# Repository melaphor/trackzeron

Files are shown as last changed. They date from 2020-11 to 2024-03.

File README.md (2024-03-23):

## ***Update 2024 March 23:* Archiving this repo** 
I was very passionate about this project when I started it in 2020, but I am no longer working on it. 

Both Azeron and QMK have made leaps and bounds in the past few years, so this incarnation of the project is behind the times. 

I think it's well past time for me to officially pass the torch to [chrisistansell](https://github.com/chrisistansell). He's adapted it for the Cyborg ***and*** adjusted the holder for a 34mm trackball, which is way more common and easily accessible than the 52mm* I used. 

**Note (because it's been asked often): I used 52mm because I wanted a very large trackball and was only considering my personal use when I started the project.*

# TRACKzeron: Adding trackball functionality to the [Azeron Keypad](https://www.azeron.eu/)

This repository contains source code and prebuilt firmware files for a modified Azeron keypad.



## Only for Classic and Compact models with TEENSY++ 2.0 mainboards

**This does not work with the Cyborg/Cyborg compact models.** It is for Azeron classic devices that use the Teensy++ 2.0 (green) mainboard. The Teensy++ 2.0 was discontinued in 2021, and Azeron started producing models with their proprietary ARM/STM32-based (black) mainboard in late-2022. I will not be adding support for the Azeron proprietary mainboards ~~and there is no ETA on a mod for Cyborg models with Teensy mainboards.~~ [Check out chrisistansell's fork for Teensy-based Cyborg support.](https://github.com/chrisistansell)

## Notes

-   This mod has no official Azeron support.
-   I had to compile custom firmware to make the trackball work, so this modded keypad does not work with the official Azeron software.
-   This mod requires soldering. (No soldering to anything on the keypad, just the sensor module)   
-   Modifying your device always comes with risk attached. I’m sharing what worked for me and offer no guarantees.

## FAQs:

### “TRACKzeron”?
Trackball + Azeron = TRACKzeron.

### Will this work on my device with a black mainboard?
The firmware will not work. The new black mainboards have a different chip. The firmware was not designed for it. I cannot confirm whether the new mainboard can be rewired to accommodate the sensor. 

### Will this work on the Azeron Cyborg or Cyborg Compact model?
No. The Cyborg models are wired differently. Unfortunately I have not figured out the rewiring and I do not have an ETA on if/when the Cyborg mod will be done.

### How did you add the trackball?
See the [guide](#guide).

### How does this work in the Azeron Software?
***This mod is not compatible with the official Azeron Software.*** You will need to use a different software to set your keybinds. I have used reWASD and JoyToKey.

### How do you use the Azeron Software with two keypads at once?
Using two keypads simultaneously isn’t officially supported by the Azeron software (yet? seems like they're working on that), even if they’re both stock firmware/not modified, but a workaround for two unmodified keypads is to plug in one keypad, set the keybinds, then unplug. Plug in the second keypad and set those keybinds. You won't be able to change the keybinds while they're both plugged in, but they should work in-game.

### Do you have a video where you’re playing with both keypads together?
Yes; there's a [YouTube clip](https://youtu.be/LT7abxc7oYk) of me playing Mass Effect Andromeda,
and some of me playing Borderlands on [my Twitch channel](https://twitch.tv/allphobic13).

### Can you make me one?
No.

## Guide

### Parts
- [Azeron Keypad](https://www.azeron.eu/) (Classic or Compact)
- [PMW3360 Motion Sensor](https://www.tindie.com/products/jkicklighter/pmw3360-motion-sensor/)   
- [3D printed trackball holder assembly](https://www.thingiverse.com/thing:4667691)
- 52mm ball: (I use the ball from an [Elecom Huge](https://elecomus.com/web/product/3271/) trackball, but I have verified that a 2 <sup>1</sup>/<sub>16</sub> inch[52.5mm] [snooker/billiard ball](https://www.johnparrottsports.com/snooker/snooker-balls/#category175) works)
- Three (3) [3mm ceramic bearing balls](https://www.bcprecision.com/products/3mm-zro2-zirconium-oxide-ceramic-ball-bearings-g5) 
- [28 AWG wire](https://www.mouser.com/c/wire-cable/hook-up-wire/?wire%20gauge%20-%20awg=28%20AWG) (I reused the wires from the thumb assembly; you'll need solder wick or a desoldering tool to reuse wire)
-  2 to 4 [M2.5x10 machine screws](https://store.azeron.eu/index.php?route=product/product&path=62&product_id=82)
- 2 M2.5 [hex nuts](https://www.mcmaster.com/nuts/hex-nuts/) if using the updated model
### Tools
- screwdrivers: hex, Philips, and flat heads 
- precision tweezers
- Soldering Iron & solder
- wire stripper
- wire cutters

### Preparing
- 3D print the trackball assembly.   
- Push the ceramic ball bearings into the trackball assembly.   
- Strip and tin 7-9 inches of 28 AWG hookup wire OR desolder the wires attached to the thumbstick and D-pad. Need 6 wires.
- Solder wires to the PMW3360 sensor pins (The other two are not used):
	- GD
	- SS    
	- SC
	- MO
	- MI    
	- VI 

### Rewire the Azeron
-   Remove the Azeron palmrest to reveal the Teensy Board

Azeron-unchanged   

- Disconnect the thumbstick and D-pad from the Teensy board and grounding block.  
- Remove the thumbstick assembly from the rail.

Azeron-removethumb

- Disconnect the pinky and ring finger switches from the Teensy board (**leave the ground [black] wires connected to the grounding block**)    
- Reconnect the pinky and ring finger switches as follows:
   	-   Ring finger:
	    - High flick/green wire: F7
	    - Flick/red wire: F6
	    - Push/orange wire: F5
	    - Pull/purple wire: F4
	-   Pinky finger:
	    - High flick/green wire: F3
	    - Flick/red wire: F2
	    - push/orange wire: F1
	    - pull/purple wire: F0

Azeron-movepinkyring

### Connect the PMW3360 Sensor:
-   Connect the sensor to the Teensy board as follows:
	- GD: GND    
	- SS: B0
	- SC: B1
	- MO: B2
	- MI: B3
	- VI: +5V
    
Azeron-addsensor
Sensor-Teensy

**NOTE:** It's important for the switches and sensor to be connected ***exactly as indicated*** or the device will not work.
- Attach the sensor to the trackball assembly. 
- Fit the trackball assembly to the Azeron thumb rail.   
- Reattach the palmrest
- Place ball in cup.
- Load firmware HEX file using the Teensy Loader.
- Enjoy trackball keypad

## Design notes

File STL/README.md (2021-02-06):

# 3D model for trackball holder

Designed to hold a 52mm ball.

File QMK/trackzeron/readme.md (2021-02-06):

# TRACKzeron

TRACKzeron

*A short description of the keyboard/project*

* Keyboard Maintainer: [MK](https://github.com/melaphor)
* Hardware Supported: Azeron Keypad modified with PMW3360 sensor
* Hardware Availability: [Azeron Offical Website](http://azeron.eu/), [PMW 3360 Motion Sensor on Tindie](https://www.tindie.com/products/jkicklighter/pmw3360-motion-sensor/)

Make example for this keyboard (after setting up your build environment):

    make trackzeron:default

Flashing example for this keyboard:

    make trackzeron:default:flash

See the [build environment setup](https://docs.qmk.fm/#/getting_started_build_tools) and the [make instructions](https://docs.qmk.fm/#/getting_started_make_guide) for more information. Brand new to QMK? Start with our [Complete Newbs Guide](https://docs.qmk.fm/#/newbs).

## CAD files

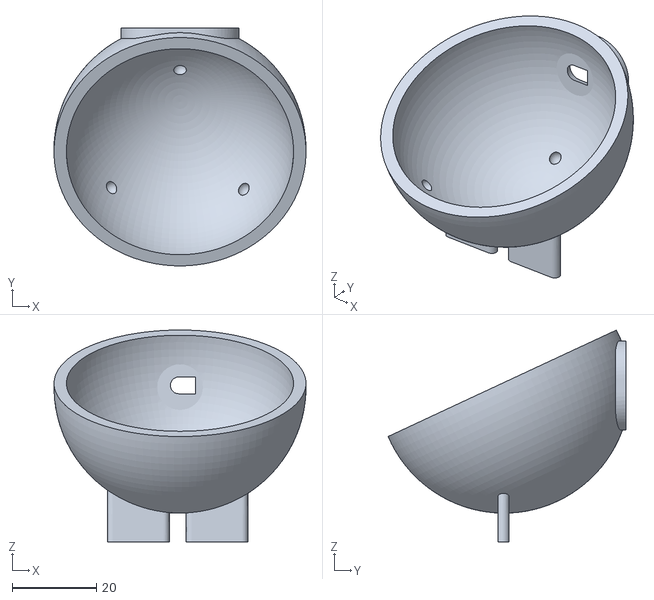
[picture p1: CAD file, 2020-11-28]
STL/Trackball_Holder.stl
60.0 x 56.6 x 50.4

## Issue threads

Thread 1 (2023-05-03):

C2 Pins still connected and using thumb button

chrisistansell, 2023-05-03:
Wanting to code in pin C2 thumb currently tagged as `NO_PIN` so I can use the switch as `KC_SPACE` (`KC_SPC`).  Is there any way you can add this to an alternate .hex file so it functions as a space bar?

chrisistansell, 2023-05-03:
config.h
line 40
NO_PIN = C2

was looking at trackzeron.h could add it in as k40?

trackzeron.h
============
line 31-43

#define LAYOUT( \
     k01, k02,           \
     k11, k12, k13, k14, \
     k21, k22, k23, k24, \
k30, k31, k32, k33, k34, \
k40, k41, k42, k43, k44 \
) { \
    {KC_NO, k01, k02, KC_NO, KC_NO}, \
    {KC_NO, k11, k12,   k13,   k14}, \
    {KC_NO, k21, k22,   k23,   k24}, \
    {k30,   k31, k32,   k33,   k34}, \
    {k40,   k41, k42,   k43,   k44} \
}

chrisistansell, 2023-05-03:
Looking in Arduino now, looks like 12 pin needs to be added to the define list.

Closed 2023-05-03.

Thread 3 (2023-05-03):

Help with customizing layout for keymap

chrisistansell, 2023-05-03:
Wondering if this is something you could help me build a .hex with
```c++
//pull
int BUTTON_T1_P1 = KEY_ESC;  //1
int BUTTON_T2_P1 = MOUSE_MIDDLE; //2
int BUTTON_T3_P1 = KEY_LEFT_ALT; //3
int BUTTON_T4_P1 = KEY_LEFT_SHIFT; //4

//side button
int BUTTON_T5_P1 = KEYPAD_TAB;  //5

//push
int BUTTON_T1_P2 = KEY_PAGE_DOWN;  //6
int BUTTON_T2_P2 = KEY_PAGE_UP;  //7
int BUTTON_T3_P2 = MOUSE_RIGHT; //8
int BUTTON_T4_P2 = MOUSE_LEFT;  //9

//flick
int BUTTON_T1_P3 = KEYPAD_1; //10
int BUTTON_T2_P3 = KEYPAD_2;    //11
int BUTTON_T3_P3 = KEYPAD_3;    //12
int BUTTON_T4_P3 = KEYPAD_4;    //13

//high flick
int BUTTON_T1_P4 = KEYPAD_5;  //14
int BUTTON_T2_P4 = KEYPAD_6;  //15
int BUTTON_T3_P4 = KEYPAD_7;  //16
int BUTTON_T4_P4 = KEYPAD_8;  //17

//highest flick
int BUTTON_T3_P5 = KEYPAD_9; //18
int BUTTON_T4_P5 = KEYPAD_0; //19

//thumb
int BUTTON_T6_P1 = KEY_SPACE; //20
```

chrisistansell, 2023-05-03:
Realizing mouse wheel and extra buttons aren't a thing we can modify.

Rebuilt the .ino file in text format, wondering if this could help?

[AzeronTrackballMod ino rebuild 5.3.23.txt](https://github.com/melaphor/trackzeron/files/11380554/AzeronTrackballMod.ino.rebuild.5.3.23.txt)

melaphor, 2023-05-03:
Did you install Teensyduino from the PJRC website?

melaphor, 2023-05-03:
Can you copy the error message(s) you're getting from Arduino?

melaphor, 2023-05-03:
I tried your Arduino code; it compiled fine when I fixed 2 things.

First: got an error `PMW3360.h: No such file or directory`. Fixed by going to the Sketch menu > Include library, then searching "PMW3360" and installing it the library.

Then I got this error:
```
error: 'KEYPAD_TAB' was not declared in this scope
note: suggested alternative: 'KEY_TAB'
```

I made the change from `KEYPAD_TAB` to `KEY_TAB`, and it worked

chrisistansell, 2023-05-03:
I must be missing a library or something.  I get the message on all of the interface keymap names. Sent from my iPhoneOn May 3, 2023, at 2:03 PM, Mars Kennedy ***@***.***> wrote:
I tried your Arduino code; it compiled fine when I fixed 2 things.
First: got an error PMW3360.h: No such file or directory. Fixed by going to the Sketch menu > Include library, then searching "PMW3360" and installing it the library.
Then I got this error:
error: 'KEYPAD_TAB' was not declared in this scope
note: suggested alternative: 'KEY_TAB'

I made the change from KEYPAD_TAB to KEY_TAB, and it worked

—Reply to this email directly, view it on GitHub, or unsubscribe.You are receiving this because you authored the thread.Message ID: ***@***.***>

melaphor, 2023-05-03:
Issue found & resolved: USB Type was set to `Serial` instead of `Serial+Keyboard+Mouse+Joystick`. Once the USB Type was changed in the Arduino IDE, code compiled.

Closed 2023-05-03.

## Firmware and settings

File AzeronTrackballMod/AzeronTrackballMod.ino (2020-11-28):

/*
  Derived from
   Azeron Simplified Firmware for XIM Apex by W11cE, 2019: 
   https://github.com/W11cE/Azeron-Simplified-Firmware-for-XIM-Apex (kept button variable names) 
   
   Sherbet Firmware by Colin Fein, 2019: 
   https://gist.github.com/Billiam/ec4ccf967088edef36e67010839f3dd1#file-sherbet-ino

 Libraries used:
  PMW3360 Module Library for Arduino by Sunjun Kim: 
  https://www.arduino.cc/reference/en/libraries/pmw3360-module/
  
  Bounce2 Library by Thomas Fredericks:
  https://github.com/thomasfredericks/Bounce2
*/

// Use USB Type: Serial+Keyboard+Mouse+Joystick

#include <PMW3360.h>
#include <Bounce2.h>

#define SS  20
#define countPerInch 1600

/*T1: pinky, T2: ring, T3: middle, T4: index, T5: side*/
/*P1: pull, P2: push, P3: flick, P4: high flick, P5: highest flick*/

#define PIN_T1_P1  38  //1
#define PIN_T2_P1 42  //2
#define PIN_T3_P1 27  //3
#define PIN_T4_P1 4 //4
#define PIN_T5_P1 11  //5
#define PIN_T1_P2 39  //6
#define PIN_T2_P2 43  //7
#define PIN_T3_P2 0 //8
#define PIN_T4_P2 5 //9
#define PIN_T1_P3 40  //10
#define PIN_T2_P3 44  //11
#define PIN_T3_P3 1 //12
#define PIN_T4_P3 8 //13
#define PIN_T1_P4 41  //14
#define PIN_T2_P4 45  //15
#define PIN_T3_P4 2 //16
#define PIN_T4_P4 9 //17
#define PIN_T3_P5 3 //18
#define PIN_T4_P5 10  //19

#define SWITCH_1    14
#define SWITCH_2    13

#define LED_1     16
#define LED_2     15
#define LED_TEENSY    6

//pull
int BUTTON_T1_P1 = KEYPAD_PERIOD;  //1
int BUTTON_T2_P1 = KEYPAD_3; //2
int BUTTON_T3_P1 = KEYPAD_2; //3
int BUTTON_T4_P1 = KEYPAD_1; //4

//side button
int BUTTON_T5_P1 = KEYPAD_4;  //5

//push
int BUTTON_T1_P2 = KEYPAD_6;  //6
int BUTTON_T2_P2 = KEYPAD_5;  //7
int BUTTON_T3_P2 = MOUSE_RIGHT; //8
int BUTTON_T4_P2 = MOUSE_LEFT;  //9

//flick
int BUTTON_T1_P3 = KEYPAD_PLUS; //10
int BUTTON_T2_P3 = KEYPAD_9;    //11
int BUTTON_T3_P3 = KEYPAD_8;    //12
int BUTTON_T4_P3 = KEYPAD_7;    //13

//high flick
int BUTTON_T1_P4 = KEYPAD_0;  //14
int BUTTON_T2_P4 = KEYPAD_SLASH;  //15
int BUTTON_T3_P4 = KEYPAD_ASTERIX;  //16
int BUTTON_T4_P4 = KEYPAD_MINUS;  //17

//highest flick
int BUTTON_T3_P5 = KEY_TAB; //18
int BUTTON_T4_P5 = KEY_PAUSE; //19

const int KB_COUNT = 17;    // Number of keyboard buttons
const int MOUSE_COUNT = 2;   // Number of mouse buttons

const int DEBOUNCE = 5;        //Adjust as needed: increase if bouncing problem, decrease if not all keypresses register; not less than 2
const int SCAN_DELAY = 5;      //Delay between scan cycles in ms

Bounce keyButtons[KB_COUNT];
Bounce mouseButtons[MOUSE_COUNT];

boolean keyStatus[KB_COUNT]; //store button status so that inputs can be released
boolean mouseStatus[MOUSE_COUNT]; //store button status so that inputs can be released

const int keyPins[] = {
           PIN_T4_P5, PIN_T3_P5, 
           PIN_T4_P4, PIN_T3_P4, PIN_T2_P4, PIN_T1_P4,
           PIN_T4_P3, PIN_T3_P3, PIN_T2_P3, PIN_T1_P3,
PIN_T5_P1,                       PIN_T2_P2, PIN_T1_P2,
           PIN_T4_P1, PIN_T3_P1, PIN_T2_P1, PIN_T1_P1
};              
const int mousePins[] = {  
          PIN_T4_P2, PIN_T3_P2
};      
//int keyMode = true; // Whether to begin in standard qwerty mode or joystick button mode



// Keycodes
const int keyLayer[] = {
           BUTTON_T4_P5, BUTTON_T3_P5, 
           BUTTON_T4_P4, BUTTON_T3_P4, BUTTON_T2_P4, BUTTON_T1_P4,
           BUTTON_T4_P3, BUTTON_T3_P3, BUTTON_T2_P3, BUTTON_T1_P3,
BUTTON_T5_P1,                       BUTTON_T2_P2, BUTTON_T1_P2,
           BUTTON_T4_P1, BUTTON_T3_P1, BUTTON_T2_P1, BUTTON_T1_P1
};              
const int mouseLayer[] = {  
          BUTTON_T4_P2, BUTTON_T3_P2
}; 

PMW3360 sensor;

void setup() {
  int i;  
  // create debouncers for mouse input pins
  for (i = 0; i < MOUSE_COUNT; i++) {
    Bounce debouncer = Bounce();

    debouncer.attach(mousePins[i], INPUT_PULLUP);
    debouncer.interval(DEBOUNCE);
    mouseButtons[i] = debouncer;
  }
  // create debouncers for keyboard input pins
  for (i = 0; i < KB_COUNT; i++) {
    Bounce debouncer = Bounce();

    debouncer.attach(keyPins[i], INPUT_PULLUP);
    debouncer.interval(DEBOUNCE);
    keyButtons[i] = debouncer;
  }
  sensor.begin(SS,countPerInch);
  digitalWrite(LED_1, HIGH); 
}

void loop() {
  scanMouse();
  scanKeyboard();
  pointerCtrl();
  delay(SCAN_DELAY);
  if (SWITCH_2 == LOW) {
    digitalWrite(LED_2, HIGH);
    };
}


void scanMouse() {
  int i;
  for (i = 0; i < MOUSE_COUNT; i++) {
    mouseButtons[i].update();
    if (mouseButtons[i].fell()) {
      mousePress(i);
    } else if (mouseButtons[i].rose()) {
      mouseRelease(i);
    }
  }
}
void scanKeyboard() {
  int i;
  for (i = 0; i < KB_COUNT; i++) {
    keyButtons[i].update();
    if (keyButtons[i].fell()) {
      keyPress(i);
    } else if (keyButtons[i].rose()) {
      keyRelease(i);
    }
  }
}
void pointerCtrl(){
    PMW3360_DATA data = sensor.readBurst();
  if(data.isOnSurface && data.isMotion)
  {
    int mdx = constrain(data.dx, -127, 127);
    int mdy = constrain(data.dy, -127, 127);

    Mouse.move(-mdx, mdy, 0);
  }
}

//Send key press event
void keyPress(int keyCode) {
  Keyboard.press(keyLayer[keyCode]);
  keyStatus[keyCode]=true;
}

//Send key release event
void keyRelease(int keyCode) {
  Keyboard.release(keyLayer[keyCode]);
  keyStatus[keyCode]=false;
}

//Send key press event
void mousePress(int keyCode) {
  Mouse.press(mouseLayer[keyCode]);
  mouseStatus[keyCode]=true;
}

//Send key release event
void mouseRelease(int keyCode) {
  Mouse.release(mouseLayer[keyCode]);
  mouseStatus[keyCode]=false;
}

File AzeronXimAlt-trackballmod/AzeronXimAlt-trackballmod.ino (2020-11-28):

/*
 * Original programming by W11cE: http://github.com/W11cE/Azeron-Simplified-Firmware-for-XIM-Apex
 * 
 * Libraries used:
 * PMW3360 Module Library for Arduino by Sunjun Kim https://www.arduino.cc/reference/en/libraries/pmw3360-module/
 */
  
#include "RefreshChecker.h"
#include <PMW3360.h>

#define ARRAY_LENGHT(type ,array)	(sizeof(array) / sizeof(type))

#define BUTTON_T4_P1  4     //index pull
#define BUTTON_T4_P2  5     //index push
#define BUTTON_T4_P3  8     //index flick 
#define BUTTON_T4_P4  9     //index high 
#define BUTTON_T4_P5  10    //index highest
#define BUTTON_T5_P1  11    //index side
#define BUTTON_T3_P1  27    //middle pull 
#define BUTTON_T3_P2  0     //middle push 
#define BUTTON_T3_P3  1     //middle flick 
#define BUTTON_T3_P4  2     //middle high 
#define BUTTON_T3_P5  3     //middle highest 
#define BUTTON_T2_P1  42     //ring pull 
#define BUTTON_T2_P2  43     //ring push 
#define BUTTON_T2_P3  44     //ring flick 
#define BUTTON_T2_P4  45     //ring high
#define BUTTON_T1_P1  38     //pinky pull 
#define BUTTON_T1_P2  39     //pinky push 
#define BUTTON_T1_P3  40     //pinky flick 
#define BUTTON_T1_P4  41     //pinky high 

const int DigitalButtons[] = {
	 BUTTON_T1_P1,
	 BUTTON_T2_P1,
	 BUTTON_T3_P1,
	 BUTTON_T4_P1,
	 BUTTON_T5_P1,
	 BUTTON_T1_P2,
	 BUTTON_T2_P2,
	 BUTTON_T3_P2,
	 BUTTON_T4_P2,
	 BUTTON_T1_P3,
	 BUTTON_T2_P3,
	 BUTTON_T3_P3,
	 BUTTON_T4_P3,
	 BUTTON_T1_P4,
	 BUTTON_T2_P4,
	 BUTTON_T3_P4,
	 BUTTON_T4_P4,
	 BUTTON_T3_P5,
	 BUTTON_T4_P5,
	};

#define SWITCH_1		14
#define SWITCH_2		13

#define LED_1			16
#define LED_2			15
#define LED_TEENSY		6

RefreshChecker Check = RefreshChecker(27);

#define SS  20 
PMW3360 sensor;

void setup()
{

Serial.begin(9600);  
  // With this line, your arduino will wait until a serial communication begin.
  // If you want your mouse application to work as soon as plug-in the USB, remove this line.
  //while(!Serial); 

  //sensor.begin(20, 1600); // to set CPI (Count per Inch), pass it as the second parameter
  if(sensor.begin(SS))  // 20 is the pin connected to SS of the module.
    Serial.println("Sensor initialization successed");
  else
    Serial.println("Sensor initialization failed");
  sensor.setCPI(1600);    // or, you can set CPI later by calling setCPI();

  Mouse.begin();
  
	Joystick.useManualSend(true);
	Joystick.hat(-1);
	Joystick.slider(512);
	Joystick.sliderLeft(0);
	Joystick.sliderRight(0);
	Joystick.Z(512);
	Joystick.Zrotate(512);

	for (int i = 0; i < ARRAY_LENGHT(int, DigitalButtons); i++)
	{
		pinMode(DigitalButtons[i], INPUT_PULLUP);
	}
	pinMode(SWITCH_1, INPUT_PULLUP);
	pinMode(SWITCH_2, INPUT_PULLUP);

	pinMode(LED_1, OUTPUT);
	pinMode(LED_2, OUTPUT);
	pinMode(LED_TEENSY, OUTPUT);

	analogWrite(LED_1, 1);
	analogWrite(LED_2, 0);
	digitalWrite(LED_TEENSY, 0);
  
}

void loop()
{
	for (int i = 0; i < ARRAY_LENGHT(int, DigitalButtons); i++)
	{
		Joystick.button(i + 1, Check.PassNew(i, !digitalReadFast(DigitalButtons[i])));
	}

	if (Check.HasNewData())
	{
		Joystick.send_now();
	}
   
   PMW3360_DATA data = sensor.readBurst();
  if(data.isOnSurface && data.isMotion)
  {
    int mdx = constrain(data.dx, -127, 127);
    int mdy = constrain(data.dy, -127, 127);

    Mouse.move(-mdx, mdy, 0);
  } 
}

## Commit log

2020-11-28 added code, prebuilt hex, and STL files
    [Trackball_Holder.stl]
2021-07-13 changed to new VID/PID
2021-07-13 Update trackzeron.json
    add new VID/PID
